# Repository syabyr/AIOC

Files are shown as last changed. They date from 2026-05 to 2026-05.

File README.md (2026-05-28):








# AIOC
This is the Ham Radio *All-in-one-Cable*. It has been in testing stage for a long time, but so far no dealbreaking issues have been found so it is pretty safe to build it. Still, please read this README carefully before ordering anything.

AIOC with Wouxun and Direwolf

## What does it do?
The AIOC is a small adapter with a USB-C connector that enumerates itself as a sound-card (e.g. for APRS purposes), a virtual tty ("COM Port") for programming and asserting the PTT (Push-To-Talk) as well as a CM108 compatible HID endpoint for CM108-style PTT (new in firmware version 1.2.0).

You can watch the videos of the *Temporarily Offline* and *HAM RADIO DUDE* YouTube channels below.

All In One Cable AIOC - Ham Nuggets Season 4 Episode 8 S04E08 (http://www.youtube.com/watch?v=RZjoPNe634o "All In One Cable AIOC - Ham Nuggets Season 4 Episode 8 S04E08")
Your BAOFENG Programming Cable Sucks! - Get This! - AIOC All in One Cable (http://www.youtube.com/watch?v=xRCmXQYRLE0 "Your BAOFENG Programming Cable Sucks! - Get This! - AIOC All in One Cable")

There is also a German 4-part article with instructions [here](https://dl-nordwest.com/index.php/2024/07/21/aioc-der-wunderadapter-fuer-handfunkgeraete-teil-1-einfuehrung-und-bestellung/).

## Features ##
- Cheap & Hackable Digital mode USB interface (similar to digirig, mobilinkd, etc...)
- Programming Cable Function via virtual Serial Port
- Compact form-factor (DIY overmolded enclosure is currently TBD)
- Based on easy-to-hack **STM32F302** with internal ADC/DAC (Programmable via USB bootloader using [DFU](#how-to-program))
- Can support Dual-PTT HTs
- Supports all popular OSes (Linux, Windows and MacOS)
  
## Compatibility
### Software
  - [Direwolf](#notes-on-direwolf) as AX.25 modem/APRS en+decoder/...
  - [AllStarLink](#notes-on-allstarlink-asl3) as ASL Node
  - [APRSdroid](#notes-on-aprsdroid) as APRS en+decoder
  - [CHIRP](#notes-on-chirp) for programming
  - [VaraFM](#notes-on-varafm)
  - ... and more

### Tested Radios (so far)
  - Wouxun UV-9D Mate (CHIRP + APRS)
  - Baofeng UV-5R (CHIRP + APRS)
  - BTECH 6X2 (CHIRP)
  - Quansheng UV-K5 ([Quansheng Dock](https://github.com/nicsure/QuanshengDock), [Egzumer](https://github.com/egzumer/uv-k5-firmware-custom) or regular)

Top side of PCB

## How To Fab
- Go to JLCPCB.com and upload the ``GERBER-k1-aioc.zip`` package (under ``kicad/k1-aioc/jlcpcb``)
  - Select PCB Thickness 1.2mm (that is what I recommend with the TRS connectors I used)
  - You may want to select LeadFree HASL
  - Select Silkscreen/Soldermask color to your liking
- Check "PCB Assembly"
  - PCBA Type "Economic"
  - Assembly Side "Top Side"
  - Tooling Holes "Added by Customer"
  - Press Confirm
  - Click "Add BOM File" and upload ``BOM-k1-aioc.csv``
  - Click "Add CPL File" and upload ``CPL-k1-aioc.csv``
  - Press Next
  - Look Through components, see if something is missing or problematic
  - **Make sure that all listed components are selected** and press Next 
  - Check everything looks roughly good (rotations are already baked-in and should be correct). Save to Cart

This gives you 5 (or more) SMD assembled AIOC. The only thing left to do is soldering on the TRS connectors (see [here](#how-to-assemble)).
The total bill should be around 60$ US for 5 pieces plus tax and shipping from China.

__Note__ that the following message from JLCPCB is okay and can be ignored.
````
The below parts won't be assembled due to data missing.
H1,H2 designators don't exist in the BOM file.
J2,D3,D4,R17 designators don't exist in the CPL file.
````

__Note__ for people doing their own PCB production: I suggest using the LCSC part numbers in the BOM file as a guide on what to buy (especially regarding the MCU). Despite the STM32F373 in the BOM, the firmware currently only supports the STM32F302 as given in the LCSC ordering information.

__Note__ As of 2025-09-25, the current hardware version is **1.2**. The minimum firmware version for this hardware version is 1.4.0. 
The following features have been added.
- Support for an external hardware input (e.g. for COS)
- A split pad for the PTT/UART contact, so in case you would like to use the AIOC hardware for another purpose than a K1-style connector, you can separate these two signals that are otherwise connected to the same TRS contact.
- Adjustable input and output audio levels (line-level, mic-level)
- A fox hunt mode, where the AIOC operates as a simple morse code beacon
  
## How To Assemble
This is the process I use for building. See photographs in ``images`` folder.
- You need to use **Monacor** ``PG-204P`` and ``PG-203P`` or compatible TRS connectors (2 solder lugs and a big tab for the sleeve connection). **Adafruit** products ``1800`` and ``1798`` are confirmed to work as well.
- Cut the 2.5mm and 3.5mm TRS sleeve tab where the hole is located
- Put both TRS connectors into the 3d-printed solder guide (or a cheap HT that you don't mind potentially damaging). Make sure, that they are seated all the way in. If the holes in the solder guide are too small, you can ream them using a 2.5mm and 3.5mm drill bit.
- Insert the AIOC PCB into the solder guide
- Solder sleeve tab on the back side for both TRS connectors first
- Turn around PCB and solder remaining solder lugs
- Optionally you can 3D print a case for your AIOC. [This model](https://www.thingiverse.com/thing:6144997) has been designed by a third party but is confirmed to work with the AIOC.

__Note__ It is unfortunately quite common that the TRS connectors have intermittent contact after soldering the ring or tip tabs. In this case, it helps to re-melt the solder joint, then using e.g. tweezer slightly assert some sideways force onto the contact and let the solder joint solidify **while applying the pressure on the contact**. This will keep some tension on the area where the tab internally connects to the barrel and thus give a solid (spring loaded) connection.

## How To Build
For building the firmware, clone the repository and initialize the submodules. Create an empty workspace with the STM32CubeIDE and import the project.
  - ``git clone <repositry url>``
  - ``git submodule update --init``
  - Start STM32CubeIDE and create a new workspace under ``<project-root>/stm32``
  - Choose File->Import and import the ``aioc-fw`` project in the same folder without copying
  - Select Project->Build All and the project should build. Use the Release build unless you specifically want to debug an issue

## How To Program
### Initial programming
The following steps are required for initial programming of the AIOC:
- Short outermost pins on the programming header. This will set the device into bootloader mode in the next step.
Shorting pins for bootloader mode
- Connect USB-C cable to the AIOC PCB
- Use a tool like ``dfu-util`` to program the firmware binary from the GitHub Releases page like this:
  ````
  dfu-util -a 0 -s 0x08000000:leave -D aioc-fw-x-y-z.bin
  ````
  __Note__ that a ``libusb`` driver is required for this. On Windows there are additional steps required as shown [here](https://yeswolf.github.io/dfu) (*DFuSe Utility and dfu-util*). On other operating systems (e.g. Linux, MacOS), this just works ™ (provided libusb is installed on your system).
  On Linux (and MacOS), your user either needs to have the permission to use libusb (``plugdev`` group) or you might need to use ``sudo``.
- Remove short from first step, unplug and replug the device, it should now enumerate as the AIOC device

### Firmware updating
Once the AIOC has firmware loaded onto it, it can be re-programmed without the above BOOT sequence by following these steps.

__Note__ This requires firmware version >= 1.2.0. For older firmwares, the initial programming sequence above is required for updating the firmware.
- Run ``dfu-util`` like this
  ````
  dfu-util -d 1209:7388 -a 0 -s 0x08000000:leave -D aioc-fw-x-y-z.bin
  ````

This will reboot the AIOC into the bootloader automatically and perform the programming. 
After that, it automatically reboots the AIOC into the newly programmed firmware.

__Note__ Should you find yourself with a bricked AIOC, use the initial programming sequence above

## How To Use
The serial interface of the AIOC enumerates as a regular COM (Windows) or ttyACM port (Linux) and can be used as such for programming the radio as well as PTT (Asserted on ``DTR=1`` and ``RTS=0``).

__Note__ before firmware version 1.2.0, PTT was asserted by ``DTR=1`` (ignoring RTS) which caused problems with certain radios when using the serial port for programming the radio e.g. using CHIRP.

The soundcard interface of the AIOC gives access to the audio data channels. It has one mono microphone channel and one mono speaker channel and currently supports the following baudrates:
  - 48000 Hz (preferred)
  - 32000 Hz
  - 24000 Hz
  - 22050 Hz (specifically for APRSdroid, has approx. 90 ppm of frequency error)
  - 16000 Hz
  - 12000 Hz
  - 11025 Hz (has approx. 90 ppm of frequency error)
  - 8000 Hz

Since firmware version 1.2.0, a CM108 style PTT interface is available for public testing. This interface works in parallel to the COM-port PTT.
Direwolf on Linux is confirmed working, please report any issues. Note that currently, Direwolf reports some warnings when using the CM108 PTT interface on the AIOC. 
While they are annoying, they are safe to ignore and require changes in the upstream direwolf sourcecode. See https://github.com/wb2osz/direwolf/issues/448 for more details.

Since firmware version 1.3.0, a HID interface is also available, that allows reconfiguration of the AIOC from the PC. There are code snippets in the Release Notes for various features.
There is also a command-line utility by Hrafnkell Eiríksson available [here](https://github.com/hrafnkelle/aioc-util).

**For advanced use of the AIOC, refer to this pinout image.**


## Notes on Direwolf
- Follow the regular setup guide with [Direwolf](https://github.com/wb2osz/direwolf) to determine the correct audio device to use. 
  For the serial and CM108 PTT interfaces on Linux, you need to set correct permissions on the ttyACM/hidraw devices. Consult Direwolf manual.
- Configure the device as follows
  ````
  [...]
  ADEVICE plughw:<x>,0  # <- Linux
  ADEVICE x 0           # <- Windows
  ARATE 48000
  [...]
  PTT CM108             # <- Use the new CM108 compatible style PTT interface
  PTT <port> DTR -RTS   # <- Alternatively use an old school serial device for PTT
  [...]
  ````

## Notes on AllStarLink (ASL3)
Once your cable is emulating a CM108, it becomes quite simple to plug into your HT and setup a simple simplex AllStarLink node that talks to your favorite repeater or node.

In `asl-menu`, set:
- Device type: `usbradio` (menu sections: 2 > A1 > N4 > I2)
- Duplex type: `1` (menu sections: 2 > A1 > N5)

Edit `usbradio.conf` (menu sections: 6 > H) (for a Puxing PX-888 cheap Chineese HT)
- `rxboost = 0`
- `rxsqhyst = 500`
- `carrierfrom = usbinvert`
- `ctcssfrom = no`
- `rxdemod = speaker`
- `txprelim = no`
- `invertptt = no`

## Notes on APRSdroid
[APRSdroid](https://aprsdroid.org/) support has been added by AIOC by implementing support for the fixed 22050 Hz sample rate that APRSdroid requires. 
It is important to notice, that the exact sample rate can not be achieved by the hardware, due to the 8 MHz crystal. 
The actual sample rate used is 22052 Hz (which represents around 90 ppm of error). From my testing this does not seem to be a problem for APRS at all.

However, since APRSdroid does not have any PTT control, sending data is currently not possible using the AIOC except using the radio VOX function. See https://github.com/ge0rg/aprsdroid/issues/324.
My previous experience is, that the Android kernel brings support for ttyACM devices (which is perfect for the AIOC) so implementing this feature for APRSdroid should theoretically be no problem.

Ideas such as implementing a digital-modes-spefic VOX-emulation to workaround this problem and let the AIOC activate the PTT automatically are currently being considered. 
Voice your opinion and ideas in the GitHub issues if this seems interesting to you.

## Notes on CHIRP
CHIRP is a very popuplar open-source programming software that supports a very wide array of HT radios. You can use CHIRP just as you would like with a regular programming cable.

Download:
  - Start CHIRP
  - Select Radio->Download from Radio
  - Select the AIOC COM/ttyACM port and start

Upload:
  - Select Radio->Upload to Radio
  - That's it

## Notes on VaraFM
Select "DTR only" for PTT Pin, so that the correct RTS/DTR sequence is generated for PTT

# Known issues
There are known issues with EMI, when using a handheld radio with a monopole (i.e. stock) antenna. In this case, the USB cable will (inadvertently) work as a tiger-tail (counterpoise) and thus, high RF currents go through the USB lines which cause issues with the USB connection. Some people have connected cables between the radio and the AIOC and put a ferrite core on those wires, which seems to reduce those issues. I am trying to find out, which of the wires between the radio and the AIOC produce the problem, so that we might add SMD ferrites on the AIOC in the future

As a workaround, you can try to reduce the transmit power or use a tiger-tail (counterpoise). Additionally, a good solution is to use a balanced antenna, such as my [EZ-Dipole](https://github.com/skuep/EZ-Dipole).

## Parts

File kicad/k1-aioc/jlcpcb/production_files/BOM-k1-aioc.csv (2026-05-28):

Comment | Designator | Footprint | LCSC
600R@100MHz | FB1,FB2 | L_0603_1608Metric | C1002
8MHz/20pF | Y1 | Crystal_SMD_5032-2Pin_5.0x3.2mm | C115962
MIC5330-SSYML | U1 | Micrel_MLF-8-1EP_2x2mm_P0.5mm_EP0.6x1.2mm | C144168
100n | C12,C15,C16,C3,C8,C9 | C_0603_1608Metric | C14663
22p/NP0 | C1,C2 | C_0603_1608Metric | C1653
4.7u/10V/X5R | C10,C13,C14,C4,C5,C6,C7 | C_0603_1608Metric | C19666
100R | R15,R17,R3,R8,R9 | R_0603_1608Metric | C22775
1.5K | R1,R10,R11,R18,R19,R4 | R_0603_1608Metric | C22843
RED | D2 | LED_0603_1608Metric | C2286
4.7K | R2 | R_0603_1608Metric | C23162
5.1K | R14,R16,R5,R6,R7 | R_0603_1608Metric | C23186
22R | R12,R13 | R_0603_1608Metric | C23345
USB4105-GF-A | J1 | USB_C_Receptacle_GCT_USB4105-xx-A_16P_TopMnt_Horizontal | C2988369
4.7n/NP0 | C11 | C_0603_1608Metric | C53987
GREEN | D1 | LED_0603_1608Metric | C72043
BC847BS | Q1 | SOT-363_SC-70-6 | C8653
STM32F373CBTx | U2 | LQFP-48_7x7mm_P0.5mm | C94046
Conn_01x07_Male | J2 | PinHeader_1x07_P1.27mm_Vertical
N.M. | D4 | LED_0603_1608Metric
N.M. | D3 | LED_0603_1608Metric

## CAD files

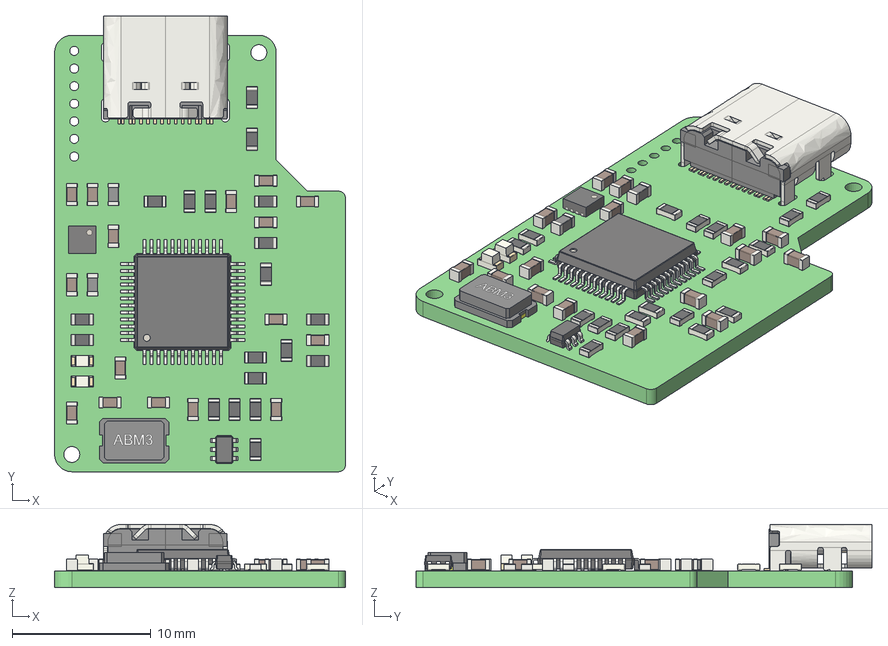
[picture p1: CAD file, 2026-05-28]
3d/k1-aioc.step
21.0 x 32.9 x 4.56 mm
k1-aioc PCB

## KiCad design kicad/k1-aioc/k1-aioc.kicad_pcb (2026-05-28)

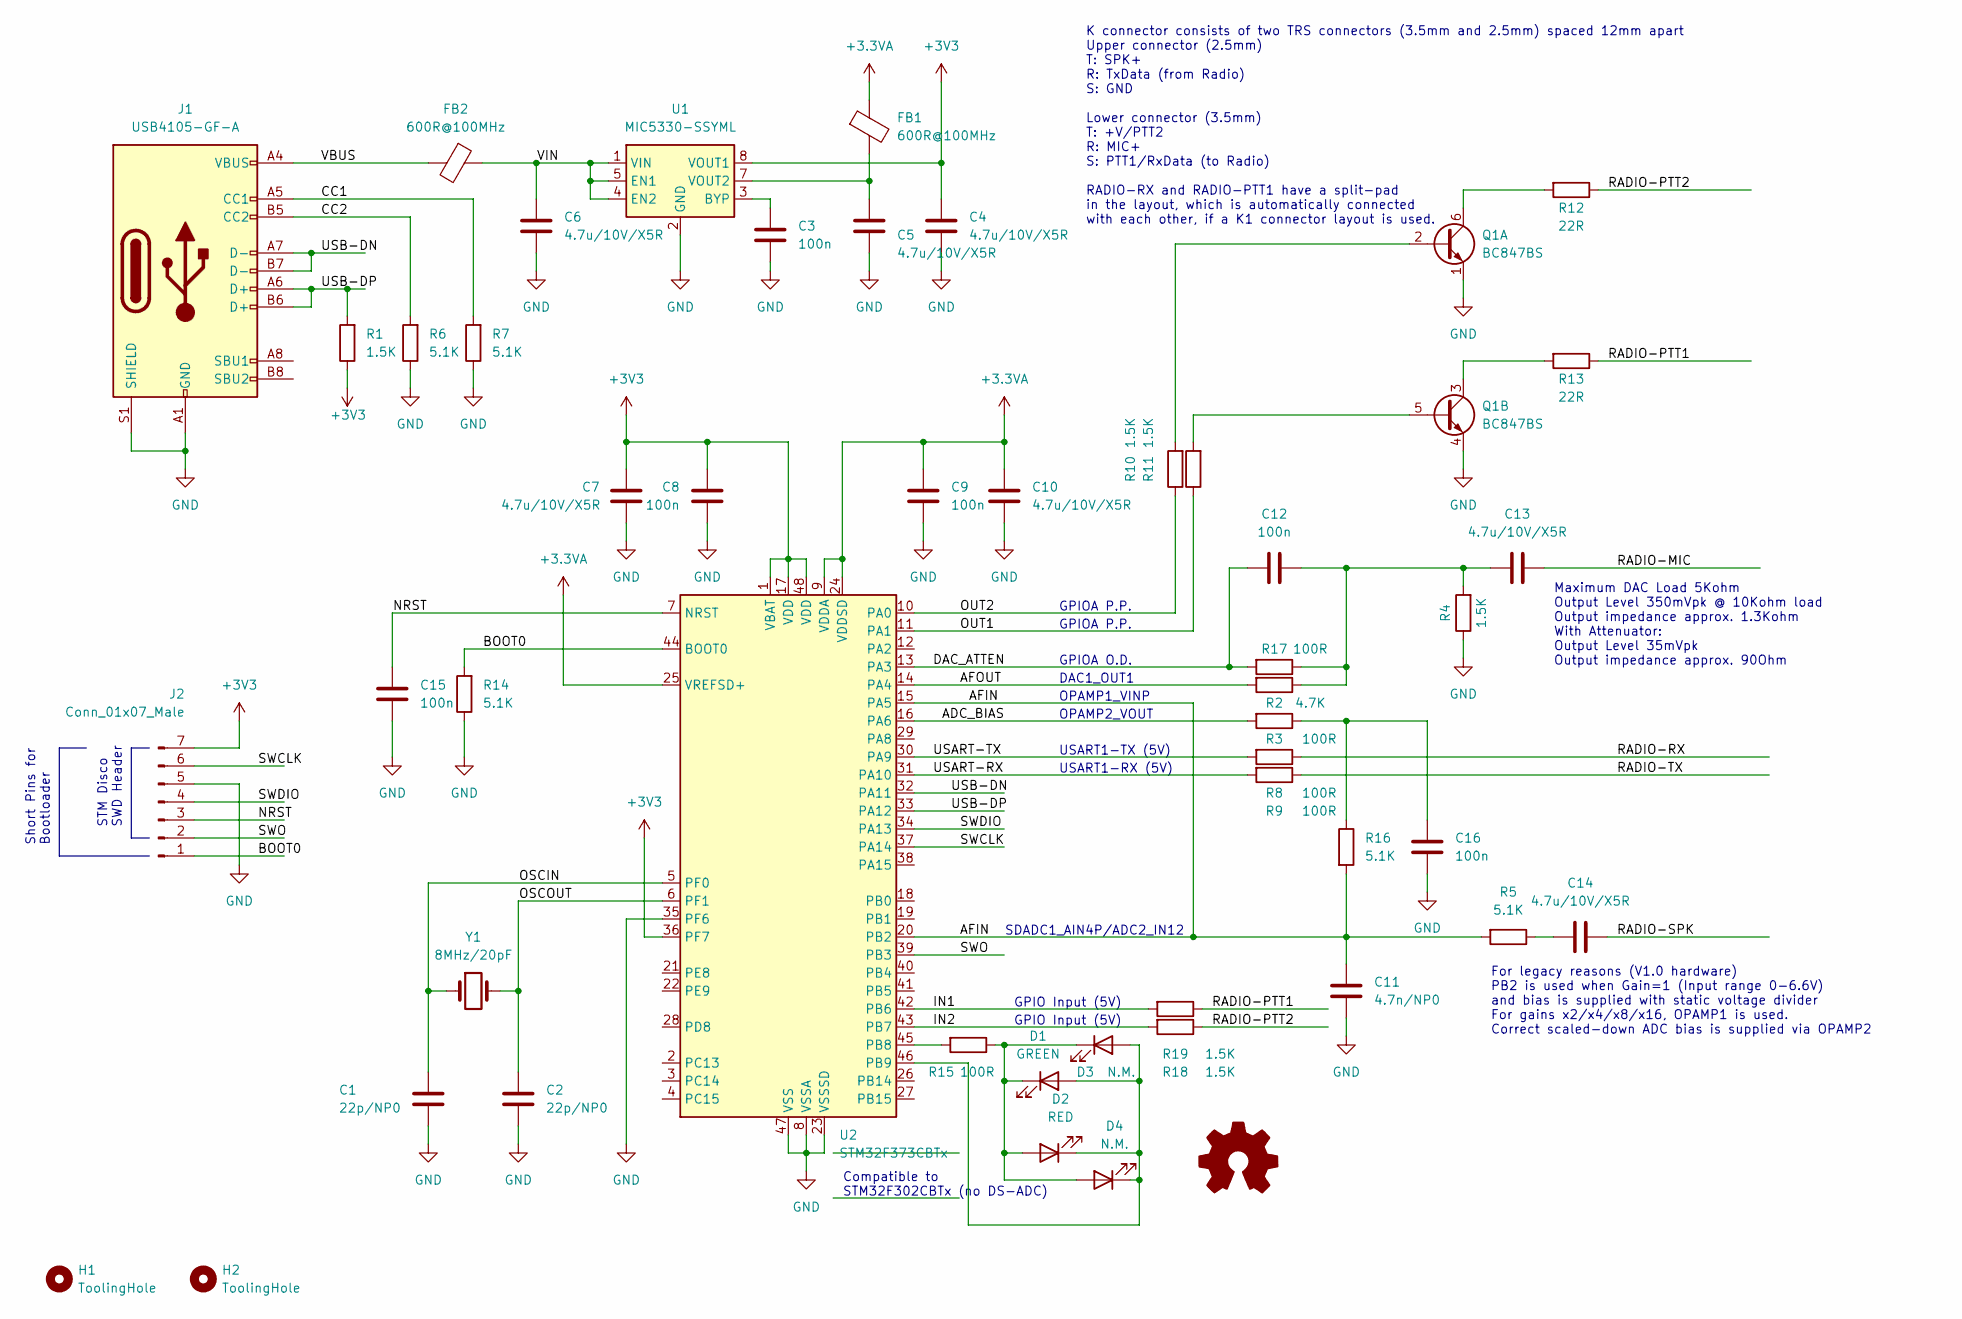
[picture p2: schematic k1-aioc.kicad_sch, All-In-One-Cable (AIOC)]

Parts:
C1, C2: 22p/NP0; C_0603_1608Metric; LCSC C1653
C3, C8, C9, C12, C15, C16: 100n; C_0603_1608Metric; LCSC C14663
C4, C5, C6, C7, C10, C13, C14: 4.7u/10V/X5R; C_0603_1608Metric; LCSC C19666
C11: 4.7n/NP0; C_0603_1608Metric; LCSC C53987
D1: GREEN; LED_0603_1608Metric; LCSC C72043
D2: RED; LED_0603_1608Metric; LCSC C2286
D3, D4: N.M.; LED_0603_1608Metric
FB1, FB2: 600R@100MHz; L_0603_1608Metric; LCSC C1002
H1, H2: ToolingHole; TOOLING-HOLE
J1: USB4105-GF-A; USB_C_Receptacle_GCT_USB4105-xx-A_16P_TopMnt_Horizontal; LCSC C2988369
J2: Conn_01x07_Male; PinHeader_1x07_P1.27mm_Vertical
Q1: BC847BS; SOT-363_SC-70-6; LCSC C8653
R1, R4, R10, R11, R18, R19: 1.5K; R_0603_1608Metric; LCSC C22843
R2: 4.7K; R_0603_1608Metric; LCSC C23162
R3, R8, R9, R15, R17: 100R; R_0603_1608Metric; LCSC C22775
R5, R6, R7, R14, R16: 5.1K; R_0603_1608Metric; LCSC C23186
R12, R13: 22R; R_0603_1608Metric; LCSC C23345
U1: MIC5330-SSYML; Micrel_MLF-8-1EP_2x2mm_P0.5mm_EP0.6x1.2mm; LCSC C144168
U2: STM32F373CBTx; LQFP-48_7x7mm_P0.5mm; LCSC C94046
Y1: 8MHz/20pF; Crystal_SMD_5032-2Pin_5.0x3.2mm; LCSC C115962

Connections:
+3.3VA: C9.1, C10.1, FB1.1, U2.9 (VDDA), U2.24 (VDDSD), U2.25 (VREFSD+)
+3V3: C4.1, C7.1, C8.1, J2.7, R1.1, U1.8 (VOUT1), U2.1 (VBAT), U2.17 (VDD), U2.36 (PF7), U2.48 (VDD)
/ADC_BIAS: R3.2, U2.16 (PA6)
/AFIN: C11.1, R5.2, R16.2, U2.15 (PA5), U2.20 (PB2)
/AFOUT: R2.2, U2.14 (PA4)
/BOOT0: J2.1, R14.2, U2.44 (BOOT0)
/CC1: J1.A5 (CC1), R7.2
/CC2: J1.B5 (CC2), R6.2
/DAC_ATTEN: C12.1, R17.2, U2.13 (PA3)
/IN1: R19.2, U2.42 (PB6)
/IN2: R18.2, U2.43 (PB7)
/NRST: C15.1, J2.3, U2.7 (NRST)
/OSCIN: C1.1, U2.5 (PF0), Y1.1
/OSCOUT: C2.1, U2.6 (PF1), Y1.2
/OUT1: R11.1, U2.11 (PA1)
/OUT2: R10.1, U2.10 (PA0)
/RADIO-MIC: C13.2
/RADIO-PTT1: R13.1, R19.1
/RADIO-PTT2: R12.1, R18.1
/RADIO-RX: R8.1
/RADIO-SPK: C14.2
/RADIO-TX: R9.1
/SWCLK: J2.6, U2.37 (PA14)
/SWDIO: J2.4, U2.34 (PA13)
/SWO: J2.2, U2.39 (PB3)
/USART-RX: R9.2, U2.31 (PA10)
/USART-TX: R8.2, U2.30 (PA9)
/USB-DN: J1.A7 (D-), J1.B7 (D-), U2.32 (PA11)
/USB-DP: J1.A6 (D+), J1.B6 (D+), R1.2, U2.33 (PA12)
/VBUS: FB2.2, J1.A4 (VBUS), J1.A9 (VBUS), J1.B4 (VBUS), J1.B9 (VBUS)
/VIN: C6.1, FB2.1, U1.1 (VIN), U1.4 (EN2), U1.5 (EN1)
GND: C1.2, C2.2, C3.2, C4.2, C5.2, C6.2, C7.2, C8.2, C9.2, C10.2, C11.2, C15.2, C16.1, J1.A1 (GND), J1.A12 (GND), J1.B1 (GND), J1.B12 (GND), J1.S1 (SHIELD), J2.5, Q1.1 (E1), Q1.4 (E2), R4.1, R6.1, R7.1, R14.1, U1.2 (GND), U1.9 (GND), U2.8 (VSSA), U2.23 (VSSSD), U2.35 (PF6), U2.47 (VSS)
unnamed: C3.1, U1.3 (BYP)
unnamed: C5.1, FB1.2, U1.7 (VOUT2)
unnamed: C12.2, C13.1, R2.1, R4.2, R17.1
unnamed: C14.1, R5.1
unnamed: C16.2, R3.1, R16.1
unnamed: D1.1 (K), D2.2 (A), D3.1 (K), D4.2 (A), R15.1
unnamed: D1.2 (A), D2.1 (K), D3.2 (A), D4.1 (K), U2.46 (PB9)
unnamed: Q1.2 (B1), R10.2
unnamed: Q1.3 (C2), R13.2
unnamed: Q1.5 (B2), R11.2
unnamed: Q1.6 (C1), R12.2
unnamed: R15.2, U2.45 (PB8)

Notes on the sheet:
STM Disco SWD Header
Short Pins for Bootloader
GPIO Input (5V)
SDADC1_AIN4P/ADC2_IN12
For legacy reasons (V1.0 hardware) PB2 is used when Gain=1 (Input range 0-6.6V) and bias is supplied with static voltage divider For gains x2/x4/x8/x16, OPAMP1 is used. Correct scaled-down ADC bias is supplied via OPAMP2
OPAMP2_VOUT
USART1-TX (5V)
OPAMP1_VINP
K connector consists of two TRS connectors (3.5mm and 2.5mm) spaced 12mm apart Upper connector (2.5mm) T: SPK+ R: TxData (from Radio) S: GND Lower connector (3.5mm) T: +V/PTT2 R: MIC+ S: PTT1/RxData (to Radio) RADIO-RX and RADIO-PTT1 have a split-pad in the layout, which is automatically connected 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
GPIOA P.P.
DAC1_OUT1
GPIOA O.D.
Compatible to STM32F302CBTx (no DS-ADC)
Maximum DAC Load 5Kohm Output Level 350mVpk @ 10Kohm load Output impedance approx. 1.3Kohm With Attenuator: Output Level 35mVpk Output impedance approx. 90Ohm
USART1-RX (5V)

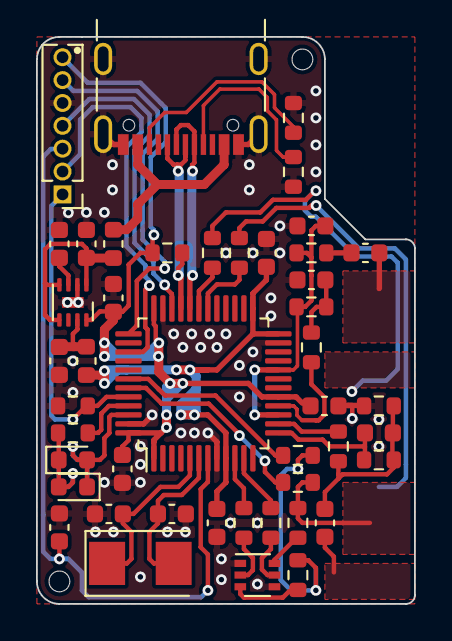
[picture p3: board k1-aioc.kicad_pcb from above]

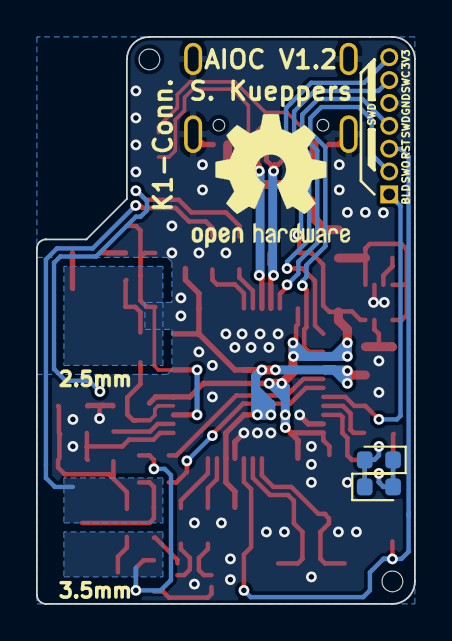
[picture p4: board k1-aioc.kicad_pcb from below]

Board: 2 copper layers, 21.0 x 31.5 mm, 49 parts (2 on the bottom side), 40 nets.

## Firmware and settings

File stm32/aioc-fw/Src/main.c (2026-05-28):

#include "stm32f3xx_hal.h"
#include "aioc.h"
#include "settings.h"
#include "led.h"
#include "usb.h"
#include "fox_hunt.h"
#include <assert.h>
#include <io.h>
#include <stdio.h>

// from ST application note AN2606
// Table 171: Bootloader device-dependent parameters
#if defined(STM32F302xB) || defined(STM32F302xC) || \
    defined(STM32F303xB) || defined(STM32F303xC) || \
    defined(STM32F373xC)
#define SYSTEM_MEMORY_BASE 0x1FFFD800
#else
#warning Live DFU reboot not supported on this MCU
#endif

#define USB_RESET_DELAY     100 /* ms */

static void SystemClock_Config(void)
{
    HAL_StatusTypeDef status;

    /* Enable external oscillator and configure PLL: 8 MHz (HSE) / 1 * 9 = 72 MHz */
    RCC_OscInitTypeDef OscConfig = {
        .OscillatorType = RCC_OSCILLATORTYPE_HSE,
        .HSEState = RCC_HSE_ON,
        .HSEPredivValue = RCC_HSE_PREDIV_DIV1,
        .PLL = {
            .PLLState = RCC_PLL_ON,
            .PLLSource = RCC_CFGR_PLLSRC_HSE_PREDIV,
            .PLLMUL = RCC_PLL_MUL9
        }
    };

    status = HAL_RCC_OscConfig(&OscConfig);
    assert(status == HAL_OK);

    /* Set correct peripheral clocks. 72 MHz (PLL) / 1.5 = 48 MHz */
    RCC_PeriphCLKInitTypeDef PeriphClk = {
        .PeriphClockSelection = RCC_PERIPHCLK_USB,
        .USBClockSelection = RCC_USBCLKSOURCE_PLL_DIV1_5
    };

    status = HAL_RCCEx_PeriphCLKConfig(&PeriphClk);
    assert(status == HAL_OK);

    /* Set up divider for maximum speeds and switch clock */
    RCC_ClkInitTypeDef ClkConfig = {
        .ClockType = RCC_CLOCKTYPE_SYSCLK | RCC_CLOCKTYPE_HCLK | RCC_CLOCKTYPE_PCLK1 | RCC_CLOCKTYPE_PCLK2,
        .SYSCLKSource = RCC_SYSCLKSOURCE_PLLCLK,
        .AHBCLKDivider = RCC_SYSCLK_DIV1,
        .APB1CLKDivider = RCC_HCLK_DIV2,
        .APB2CLKDivider = RCC_HCLK_DIV1
    };

   status = HAL_RCC_ClockConfig(&ClkConfig, FLASH_LATENCY_2);
   assert(status == HAL_OK);

    NVIC_SetPriority(SysTick_IRQn, AIOC_IRQ_PRIO_SYSTICK);

    /* Enable MCO Pin to PLL/2 output */
    __HAL_RCC_GPIOA_CLK_ENABLE();

    GPIO_InitTypeDef GpioInit = {
        .Pin = GPIO_PIN_8,
        .Mode = GPIO_MODE_AF_PP,
        .Pull = GPIO_NOPULL,
        .Speed = GPIO_SPEED_FREQ_HIGH,
        .Alternate = GPIO_AF0_MCO
    };

    HAL_GPIO_Init(GPIOA, &GpioInit);
    HAL_RCC_MCOConfig(RCC_MCO1, RCC_MCO1SOURCE_PLLCLK_DIV2, RCC_MCODIV_1);
}

static void SystemReset(void) {
    uint32_t resetFlags = RCC->CSR;

    /* Clear reset flags */
    RCC->CSR |= RCC_CSR_RMVF;

    /* Reset USB if necessary */
    if (!(resetFlags & RCC_CSR_PORRSTF)) {
        /* Since the USB Pullup is hardwired to the supply voltage,
         * the host (re-)enumerates our USB device only during Power-On-Reset.
         * For all other reset causes, do a manual USB reset. */
        USB_Reset();
#if 1
        /* Use SysTick to delay before continuing */
        SysTick->LOAD  = ((uint32_t) USB_RESET_DELAY * (HAL_RCC_GetHCLKFreq() / 1000)) - 1;
        SysTick->CTRL  = SysTick_CTRL_CLKSOURCE_Msk | SysTick_CTRL_ENABLE_Msk;

        while (! (SysTick->CTRL & SysTick_CTRL_COUNTFLAG_Msk) )
            /* Wait for timer expiration */;

        SysTick->CTRL  = 0x00000000; /* Reset SysTick */
#endif
    }

    if (resetFlags & RCC_CSR_WWDGRSTF) {
#if defined(SYSTEM_MEMORY_BASE)
        /* Reset cause was watchdog, which is used for rebooting into the bootloader.
           Set stack pointer to *SYSTEM_MEMORY_BASE
           and jump to *(SYSTEM_MEMORY_BASE + 4)
           https://stackoverflow.com/a/42031657 */
        asm volatile (
            "  msr     msp, %[sp]      \n"
            "  bx      %[pc]           \n"

            :: [sp] "r" (*( (uint32_t*)(SYSTEM_MEMORY_BASE)     )),
               [pc] "r" (*( (uint32_t*)(SYSTEM_MEMORY_BASE + 4) ))
        );
#else
    while(1)
        ;
#endif
    }

    /* Initialize HAL */
    HAL_Init();

    /* Enable Clock to SYSCFG */
    __HAL_RCC_SYSCFG_CLK_ENABLE();

    /* Enable SWO debug output */
    __HAL_RCC_GPIOB_CLK_ENABLE();
    GPIO_InitTypeDef GpioSWOInit = {
        .Pin = GPIO_PIN_3,
        .Mode = GPIO_MODE_AF_PP,
        .Pull = GPIO_NOPULL,
        .Speed = GPIO_SPEED_FREQ_LOW,
        .Alternate = GPIO_AF0_TRACE
    };
    HAL_GPIO_Init(GPIOB, &GpioSWOInit);
}

int _write(int file, char *ptr, int len)
{
	for (uint32_t i=0; i<len; i++) {
		ITM_SendChar(*ptr++);
	}

	return len;
}

void _close(void)
{
}

void _lseek(void)
{
}

void _read(void)
{
}

void _fstat(void)
{
}

void _getpid(void)
{
}

void _isatty(void)
{
}

void _kill(void)
{
}

int main(void)
{
    SystemReset();
    SystemClock_Config();

    Settings_Init();

    LED_Init();
    LED_MODE(0, LED_MODE_SLOWPULSE2X);
    LED_MODE(1, LED_MODE_SLOWPULSE2X);

    IO_Init();

    USB_Init();

    FoxHunt_Init();

    /* Enable indepedent watchdog to reset on lockup*/
    IWDG_HandleTypeDef IWDGHandle = {
        .Instance = IWDG,
        .Init = {
            .Prescaler = IWDG_PRESCALER_8,
            .Reload = 0x02FF,
            .Window = 0x0FFF
        }
    };
    HAL_IWDG_Init(&IWDGHandle);

    while (1) {
        USB_Task();

        static uint32_t lastTick = 0;
        uint32_t nowTick = HAL_GetTick();

        if ((nowTick - lastTick) >= 1000) {
            lastTick = nowTick;

            /* 1 second timebase */
            FoxHunt_Tick();


            usb_audio_fbstats_t fb;
            USB_AudioGetSpeakerFeedbackStats(&fb);

            usb_audio_bufstats_t buf;
            USB_AudioGetSpeakerBufferStats(&buf);

#if 0
            printf("buf: (%d/%d/%d) fb: (%06lX/%06lX/%06lX)\n",
                    buf.bufLevelMin, buf.bufLevelMax, buf.bufLevelAvg,
                    fb.feedbackMin, fb.feedbackMax, fb.feedbackAvg);
#endif
        }

        HAL_IWDG_Refresh(&IWDGHandle);
    }

  return 0;
}

void NMI_Handler(void) {
}

void HardFault_Handler(void) {
    /* Go to infinite loop when Hard Fault exception occurs */
    while (1) {
    }
}

void MemManage_Handler(void) {
    /* Go to infinite loop when Memory Manage exception occurs */
    while (1) {
    }
}

void BusFault_Handler(void) {
    /* Go to infinite loop when Bus Fault exception occurs */
    while (1) {
    }
}

void UsageFault_Handler(void) {
    /* Go to infinite loop when Usage Fault exception occurs */
    while (1) {
    }
}

void SVC_Handler(void) {
}

void DebugMon_Handler(void) {
}

void PendSV_Handler(void) {
}

void SysTick_Handler(void) {
    HAL_IncTick();
}

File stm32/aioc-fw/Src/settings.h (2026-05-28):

#ifndef SETTINGS_H_
#define SETTINGS_H_

#include <stdint.h>
#include "usb_descriptors.h"


#define SETTINGS_GET(REG, FIELD) ((settingsRegMap[REG] & (REG##_##FIELD##_##MASK)) >> (REG##_##FIELD##_##OFFS))

#define SETTINGS_REGMAP_SIZE     256
#define SETTINGS_REGMAP_READONLYADDR 0xC0

extern uint32_t settingsRegMap[SETTINGS_REGMAP_SIZE];

/* Magic number register. Mainly used to see if flash data is valid */
#define SETTINGS_REG_MAGIC                                  0x00
#define SETTINGS_REG_MAGIC_DEFAULT                          ( (((uint32_t) 'A') <<  0) | \
                                                              (((uint32_t) 'I') <<  8) | \
                                                              (((uint32_t) 'O') << 16) | \
                                                              (((uint32_t) 'C') << 24) )

/* USB ID register. The default USB VID and PID can be overwritten. Use with caution */
#define SETTINGS_REG_USBID                                  0x08
#define SETTINGS_REG_USBID_DEFAULT                          (SETTINGS_REG_USBID_VID_DFLT | SETTINGS_REG_USBID_PID_DFLT)
/* VID: USB Vendor Id */
#define SETTINGS_REG_USBID_VID_DFLT                         ((uint32_t) USB_VID << SETTINGS_REG_USBID_VID_OFFS)
#define SETTINGS_REG_USBID_VID_OFFS                         0
#define SETTINGS_REG_USBID_VID_MASK                         0x0000FFFFUL
/* PID: USB Product Id */
#define SETTINGS_REG_USBID_PID_DFLT                         ((uint32_t) USB_PID << SETTINGS_REG_USBID_PID_OFFS)
#define SETTINGS_REG_USBID_PID_OFFS                         16
#define SETTINGS_REG_USBID_PID_MASK                         0xFFFF0000UL

/* AIOC IOMUX0 register */
#define SETTINGS_REG_AIOC_IOMUX0                            0x24
#define SETTINGS_REG_AIOC_IOMUX0_DEFAULT                    (SETTINGS_REG_AIOC_IOMUX0_OUT1SRC_DFLT)
/* OUT1SRC: Source for OUT1 signal */
#define SETTINGS_REG_AIOC_IOMUX0_OUT1SRC_DFLT               (SETTINGS_REG_AIOC_IOMUX0_OUT1SRC_CM108GPIO3_MASK | SETTINGS_REG_AIOC_IOMUX0_OUT1SRC_SERIALDTRNRTS_MASK)
#define SETTINGS_REG_AIOC_IOMUX0_OUT1SRC_OFFS               0
#define SETTINGS_REG_AIOC_IOMUX0_OUT1SRC_MASK               0xFFFFFFFFUL
#define SETTINGS_REG_AIOC_IOMUX0_OUT1SRC_NONE_MASK          0x00000000UL
#define SETTINGS_REG_AIOC_IOMUX0_OUT1SRC_CM108GPIO1_MASK    0x00000001UL
#define SETTINGS_REG_AIOC_IOMUX0_OUT1SRC_CM108GPIO2_MASK    0x00000002UL
#define SETTINGS_REG_AIOC_IOMUX0_OUT1SRC_CM108GPIO3_MASK    0x00000004UL
#define SETTINGS_REG_AIOC_IOMUX0_OUT1SRC_CM108GPIO4_MASK    0x00000008UL
#define SETTINGS_REG_AIOC_IOMUX0_OUT1SRC_SERIALDTR_MASK     0x00000100UL
#define SETTINGS_REG_AIOC_IOMUX0_OUT1SRC_SERIALRTS_MASK     0x00000200UL
#define SETTINGS_REG_AIOC_IOMUX0_OUT1SRC_SERIALDTRNRTS_MASK 0x00000400UL
#define SETTINGS_REG_AIOC_IOMUX0_OUT1SRC_SERIALNDTRRTS_MASK 0x00000800UL
#define SETTINGS_REG_AIOC_IOMUX0_OUT1SRC_VPTT_MASK          0x00001000UL

/* AIOC IOMUX1 register */
#define SETTINGS_REG_AIOC_IOMUX1                            0x25
#define SETTINGS_REG_AIOC_IOMUX1_DEFAULT                    (SETTINGS_REG_AIOC_IOMUX1_OUT2SRC_DFLT)
/* OUT2SRC: Source for OUT2 signal */
#define SETTINGS_REG_AIOC_IOMUX1_OUT2SRC_DFLT               (SETTINGS_REG_AIOC_IOMUX1_OUT2SRC_CM108GPIO4_MASK)
#define SETTINGS_REG_AIOC_IOMUX1_OUT2SRC_OFFS               SETTINGS_REG_AIOC_IOMUX0_OUT1SRC_OFFS
#define SETTINGS_REG_AIOC_IOMUX1_OUT2SRC_MASK               SETTINGS_REG_AIOC_IOMUX0_OUT1SRC_MASK
#define SETTINGS_REG_AIOC_IOMUX1_OUT2SRC_NONE_MASK          SETTINGS_REG_AIOC_IOMUX0_OUT1SRC_NONE_MASK
#define SETTINGS_REG_AIOC_IOMUX1_OUT2SRC_CM108GPIO1_MASK    SETTINGS_REG_AIOC_IOMUX0_OUT1SRC_CM108GPIO1_MASK
#define SETTINGS_REG_AIOC_IOMUX1_OUT2SRC_CM108GPIO2_MASK    SETTINGS_REG_AIOC_IOMUX0_OUT1SRC_CM108GPIO2_MASK
#define SETTINGS_REG_AIOC_IOMUX1_OUT2SRC_CM108GPIO3_MASK    SETTINGS_REG_AIOC_IOMUX0_OUT1SRC_CM108GPIO3_MASK
#define SETTINGS_REG_AIOC_IOMUX1_OUT2SRC_CM108GPIO4_MASK    SETTINGS_REG_AIOC_IOMUX0_OUT1SRC_CM108GPIO4_MASK
#define SETTINGS_REG_AIOC_IOMUX1_OUT2SRC_SERIALDTR_MASK     SETTINGS_REG_AIOC_IOMUX0_OUT1SRC_SERIALDTR_MASK
#define SETTINGS_REG_AIOC_IOMUX1_OUT2SRC_SERIALRTS_MASK     SETTINGS_REG_AIOC_IOMUX0_OUT1SRC_SERIALRTS_MASK
#define SETTINGS_REG_AIOC_IOMUX1_OUT2SRC_SERIALDTRNRTS_MASK SETTINGS_REG_AIOC_IOMUX0_OUT1SRC_SERIALDTRNRTS_MASK
#define SETTINGS_REG_AIOC_IOMUX1_OUT2SRC_SERIALNDTRRTS_MASK SETTINGS_REG_AIOC_IOMUX0_OUT1SRC_SERIALNDTRRTS_MASK
#define SETTINGS_REG_AIOC_IOMUX1_OUT2SRC_VPTT_MASK          SETTINGS_REG_AIOC_IOMUX0_OUT1SRC_VPTT_MASK
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

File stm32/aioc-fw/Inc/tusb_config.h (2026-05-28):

/*
 * The MIT License (MIT)
 *
 * Copyright (c) 2019 Ha Thach (tinyusb.org)
 *
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
 */

#ifndef _TUSB_CONFIG_H_
#define _TUSB_CONFIG_H_

#ifdef __cplusplus
 extern "C" {
#endif

//--------------------------------------------------------------------+
// Board Specific Configuration
//--------------------------------------------------------------------+

// RHPort number used for device can be defined by board.mk, default to port 0
#ifndef BOARD_TUD_RHPORT
#define BOARD_TUD_RHPORT      0
#endif

// RHPort max operational speed can defined by board.mk
#ifndef BOARD_TUD_MAX_SPEED
#define BOARD_TUD_MAX_SPEED   OPT_MODE_FULL_SPEED
#endif

#ifndef MAX_EP_COUNT
#define MAX_EP_COUNT 8
#endif

//--------------------------------------------------------------------
// COMMON CONFIGURATION
//--------------------------------------------------------------------

// defined by board.mk
#ifndef CFG_TUSB_MCU
#error CFG_TUSB_MCU must be defined
#endif

#ifndef CFG_TUSB_OS
#define CFG_TUSB_OS           OPT_OS_NONE
#endif

#ifndef CFG_TUSB_DEBUG
#define CFG_TUSB_DEBUG        0
#endif

// Enable Device stack
#define CFG_TUD_ENABLED       1

// Default is max speed that hardware controller could support with on-chip PHY
#define CFG_TUD_MAX_SPEED     BOARD_TUD_MAX_SPEED

/* USB DMA on some MCUs can only access a specific SRAM region with restriction on alignment.
 * Tinyusb use follows macros to declare transferring memory so that they can be put
 * into those specific section.
 * e.g
 * - CFG_TUSB_MEM SECTION : __attribute__ (( section(".usb_ram") ))
 * - CFG_TUSB_MEM_ALIGN   : __attribute__ ((aligned(4)))
 */
#ifndef CFG_TUSB_MEM_SECTION
#define CFG_TUSB_MEM_SECTION
#endif

#ifndef CFG_TUSB_MEM_ALIGN
#define CFG_TUSB_MEM_ALIGN          __attribute__ ((aligned(4)))
#endif

//--------------------------------------------------------------------
// DEVICE CONFIGURATION
//--------------------------------------------------------------------

#ifndef CFG_TUD_ENDPOINT0_SIZE
#define CFG_TUD_ENDPOINT0_SIZE    8
#endif

//------------- CLASS -------------//
#define CFG_TUD_AUDIO             1
#define CFG_TUD_CDC               1
#define CFG_TUD_HID               1
#define CFG_TUD_DFU_RUNTIME       1

// CDC FIFO size of TX and RX
#define CFG_TUD_CDC_RX_BUFSIZE   512
#define CFG_TUD_CDC_TX_BUFSIZE   512

// CDC Endpoint transfer buffer size, more is faster
#define CFG_TUD_CDC_EP_BUFSIZE   64

// HID buffer size
#define CFG_TUD_HID_EP_BUFSIZE   8

 //--------------------------------------------------------------------
 // AUDIO CLASS DRIVER CONFIGURATION
 //--------------------------------------------------------------------

 // Have a look into audio_device.h for all configurations

#define CFG_TUD_AUDIO_ENABLE_EP_IN                                    1
#define CFG_TUD_AUDIO_ENABLE_EP_OUT                                   1
#define CFG_TUD_AUDIO_ENABLE_FEEDBACK_EP                              1

#define CFG_TUD_AUDIO_FUNC_1_DESC_LEN                                 AIOC_AUDIO_DESC_LEN
#define CFG_TUD_AUDIO_FUNC_1_N_AS_INT                                 1
#define CFG_TUD_AUDIO_FUNC_1_CTRL_BUF_SZ                              64
#define CFG_TUD_AUDIO_FUNC_1_N_BYTES_PER_SAMPLE                       2
#define CFG_TUD_AUDIO_FUNC_1_N_CHANNELS_TX                            1
#define CFG_TUD_AUDIO_FUNC_1_N_CHANNELS_RX                            1
#define CFG_TUD_AUDIO_FUNC_1_EP_OUT_SZ_MAX                            CFG_TUD_AUDIO_EP_SZ_OUT + CFG_TUD_AUDIO_FUNC_1_N_BYTES_PER_SAMPLE * CFG_TUD_AUDIO_FUNC_1_N_CHANNELS_RX
#define CFG_TUD_AUDIO_FUNC_1_EP_OUT_SW_BUF_SZ                         1024 /* FIFO not being power of 2 seem to result in all kinds of BusFaults? */
#define CFG_TUD_AUDIO_FUNC_1_EP_IN_SZ_MAX                             CFG_TUD_AUDIO_EP_SZ_IN + CFG_TUD_AUDIO_FUNC_1_N_BYTES_PER_SAMPLE * CFG_TUD_AUDIO_FUNC_1_N_CHANNELS_TX
#define CFG_TUD_AUDIO_FUNC_1_EP_IN_SW_BUF_SZ                          1024

#define CFG_TUD_AUDIO_EP_SZ_IN                                        (48) * CFG_TUD_AUDIO_FUNC_1_N_BYTES_PER_SAMPLE * CFG_TUD_AUDIO_FUNC_1_N_CHANNELS_TX      // 48 Samples (48 kHz) x 2 Bytes/Sample x 1 Channel
#define CFG_TUD_AUDIO_EP_SZ_OUT                                       (48) * CFG_TUD_AUDIO_FUNC_1_N_BYTES_PER_SAMPLE * CFG_TUD_AUDIO_FUNC_1_N_CHANNELS_RX      // 48 Samples (48 kHz) x 2 Bytes/Sample x 1 Channel

/* Include this here for pulling length of custom descriptors into tinyusb stack */
#include "usb_descriptors.h"

#ifdef __cplusplus
 }
#endif

#endif /* _TUSB_CONFIG_H_ */
